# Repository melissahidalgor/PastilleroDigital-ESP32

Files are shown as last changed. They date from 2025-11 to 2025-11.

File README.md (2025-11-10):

# 💊 Proyecto: Pastillero Digital con Web Server 

## Resumen del Proyecto

El Pastillero Digital actúa como como un recordatorio de medicación y un recolector de datos para resolver la problemática de las personas que olvidan tomar sus medicamentos.

El sistema utiliza un microcontrolador ESP32 para controlar los componentes físicos (pantalla, alarma y sensores de peso) y simultáneamente aloja un Web Server para la administración remota de la medicación a través de una página web.

## 💻 Hardware y Componentes

| Componente | Conexión/ Tecnología| Función Principal |
| :--- | :---: | :--- |
| **ESP32 S3** | Microcontrolador | Utilizado por su capacidad Wi-Fi  y alto rendimiento |
| **Galgas** | Puente de Wheatstone / HX711 (ADC) | Sensores de presión que detectan la presencia o el retiro de pastillas en cada compartimento |
| **Pantalla LCD TFT** | LVGL (Librería de GUI) / SPI | Visualiza la hora, fecha y la siguiente pastilla a tomar |
| **Buzzer** | Salida Digital | Activa una alarma sonora cuando llega la hora de la toma |
| **Batería de Litio (250 mAh)** |  | Autonomía para el uso portable |
| **TP4056** |  | Módulo de carga y descarga de batería |

## Desarrollo Web (Web Server)

El ESP32 aloja un servidor web para la administración remota. Se usan SPIFFS (Serial Peripheral Interface Flash File System) para almacenar y servir todos los archivos estáticos de la interfaz web en la ESP32.

| Archivo | Tecnología| Función Principal |
| :--- | :---: | :--- |
| **index.html** | HTML5 |Estructura de la interfaz de usuario |
| **estilos.css** | CSS3 |Estilos y presentación de la página |
| **script.js** | JavaScript |Lógica de negocio: Gestión local (localStorage), cálculo de tomas futuras, y comunicación asíncrona (Fetch) con el ESP32. |

## ⚙️ Características de la Programación 
* **Detección de toma de pastilla:** Se utiliza un algoritmo de detección de cambio por umbral y un tiempo de confirmación de 5 segundos para validar que una pastilla fue retirada.

* **Comunicación Cliente-Servidor:**   `handleRecibirProximaToma()`: Recibe los datos de la próxima dosis desde la página web y los almacena en el ESP32.

  `handleGetTomaNotificacion()`: Permite a la página web hacer polling al ESP32 para saber si se ha detectado una toma física, enviando la confirmación de regreso para actualizar el historial.

* **Gestión de Tiempo:** Se utiliza el protocolo NTP para obtener la hora y fecha actual

* **Interfaz de Usuario Embebida:** Implementación de la librería LVGL para renderizar la interfaz en el LCD TFT

## 🖼️ Montaje

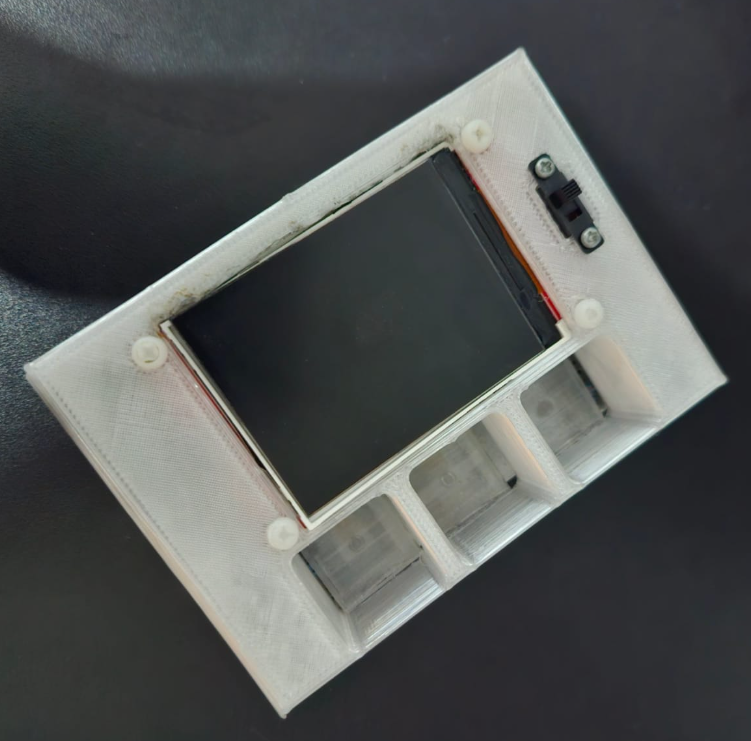
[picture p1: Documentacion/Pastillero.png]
texto alternativo


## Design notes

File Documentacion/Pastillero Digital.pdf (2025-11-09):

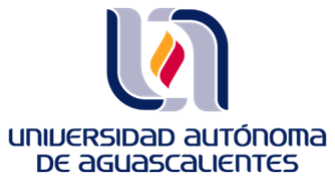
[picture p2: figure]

### CENTRO DE CIENCIAS BÁSICAS

### DEPARTAMENTO DE SISTEMÁS ELECTRÓNICOS

### INGENIERÍA EN ELECTRÓNICA

### CONTROL DISCRETO

## PROYECTO FINAL

## PASTILLERO DIGITAL

INTEGRANTES:

JORGE EDUARDO FUANTOS DÍAZ

MELISSA HIDALGO RODRÍGUEZ

HAEL BARUC MARTINEZ CHAVEZ

DOCENTE: FABIOLA FRAGOSO SALAS

FECHA: 13/06/25

# INDICE

DESCRIPCIÓN DEL PROYECTO:

El pastillero digital es un sistema que cuenta con tres compartimentos para almacenar pastillas, una pantalla LCD para visualizar la siguiente pastilla a ser tomada, sensores de presión para detectar las pastillas y la conexión a una página web para administrar las pastillas tomadas y por tomar.

MOTIVACIÓN:

Nuestro proyecto consistió en crear un pastillero recordatorio y recolector de datos. Nuestra motivación es ofrecer un pastillero con un sistema encargado de recordar la medicación de los usuarios, ser económico, ergonómico y accesible para todo el mercado.
La problemática que solucionamos en gran parte es que las personas mayores pueden tener perdidas de memoria que les impide tomar sus medicamentos a tiempo.

TEMAS DEL CURSO APLICADOS:

El principal tema aplicado fue el muestreo para determinar la frecuencia de muestro en las galgas y para saber el tiempo de polling de la página web a la ESP32.

DESARROLLO DEL PROYECTO:

Para el desarrollo de nuestro proyecto nos enfocamos en 3 fases: planeación, desarrollo e implementación.
En la planeación del proyecto planteamos materiales con los que vamos a trabajar, plan de trabajo, secciones del proyecto y sus riesgos.
Diagramas de bloques para las conexiones eléctricas:

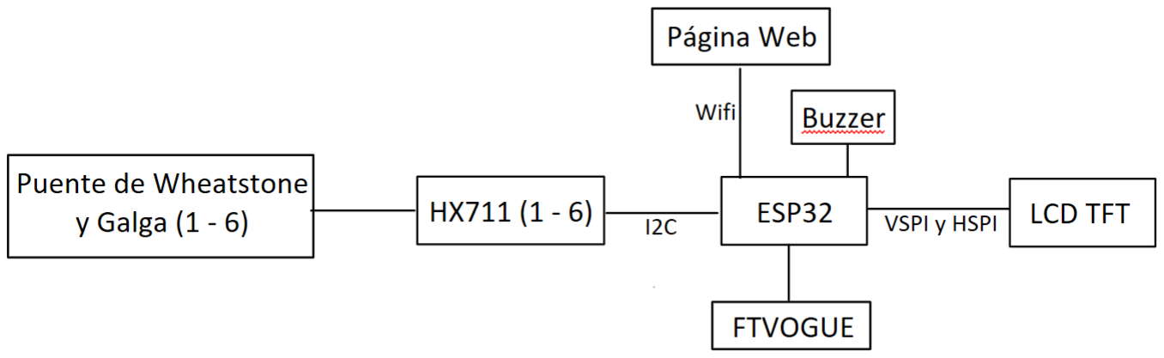
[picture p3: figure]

Figura 1: Diagrama a bloques

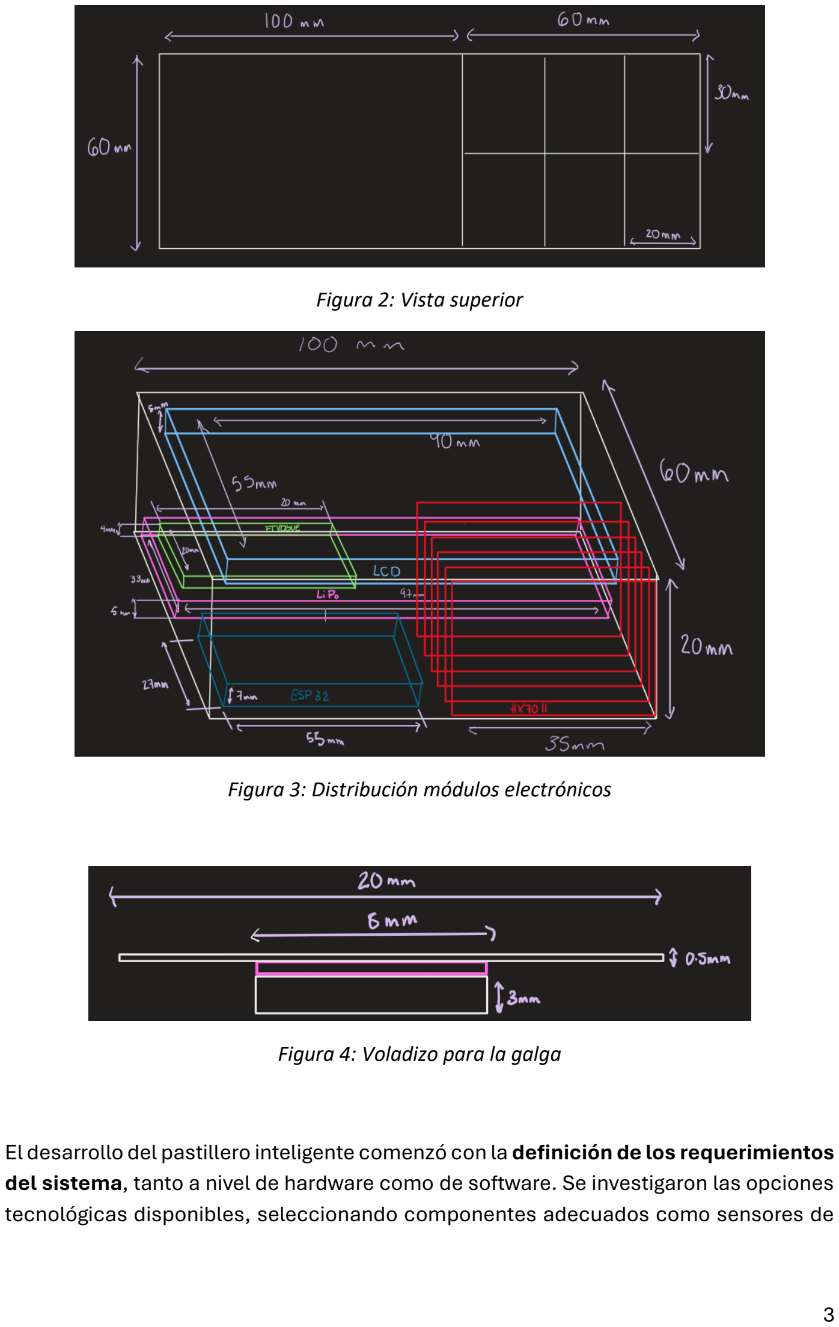
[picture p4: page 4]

Figura 2: Vista superior

Figura 3: Distribución módulos electrónicos

Figura 4: Voladizo para la galga

El desarrollo del pastillero inteligente comenzó con la definición de los requerimientos del sistema, tanto a nivel de hardware como de software. Se investigaron las opciones tecnológicas disponibles, seleccionando componentes adecuados como sensores de peso, pantallas LCD y microcontroladores con conectividad. A partir de ello, se estableció un esquema de funcionamiento general mediante un diagrama de bloques.

Una vez identificados los componentes, se procedió con la revisión de materiales y adquisición de los elementos electrónicos y mecánicos necesarios para los primeros prototipos. Paralelamente, se realizó documentación inicial del proyecto.

Luego, se diseñó el circuito electrónico preliminar, se elaboró un primer boceto físico del pastillero y se planificó la estructura del código con las funcionalidades deseadas. En esta etapa también se modeló en 3D la carcasa del dispositivo, se desarrolló el esquemático del circuito y se inició la creación de la interfaz de usuario.

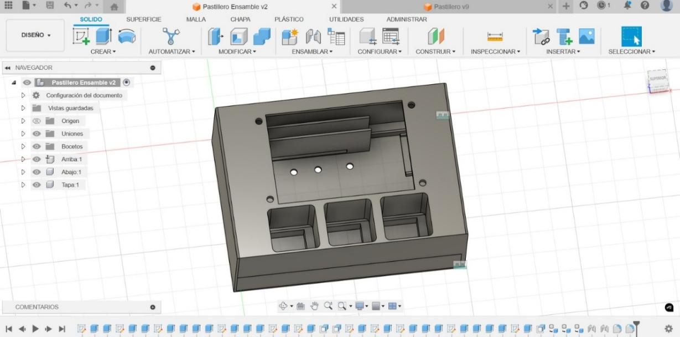
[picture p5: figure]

Figura 5: Diseño del pastillero en 3D

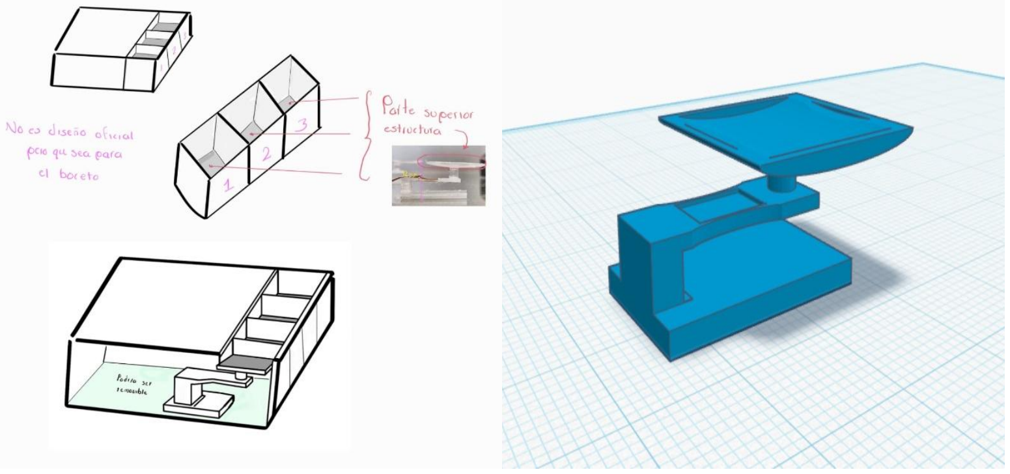
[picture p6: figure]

Figura 6: Diseño del pastillero junto con el sistema de galgas

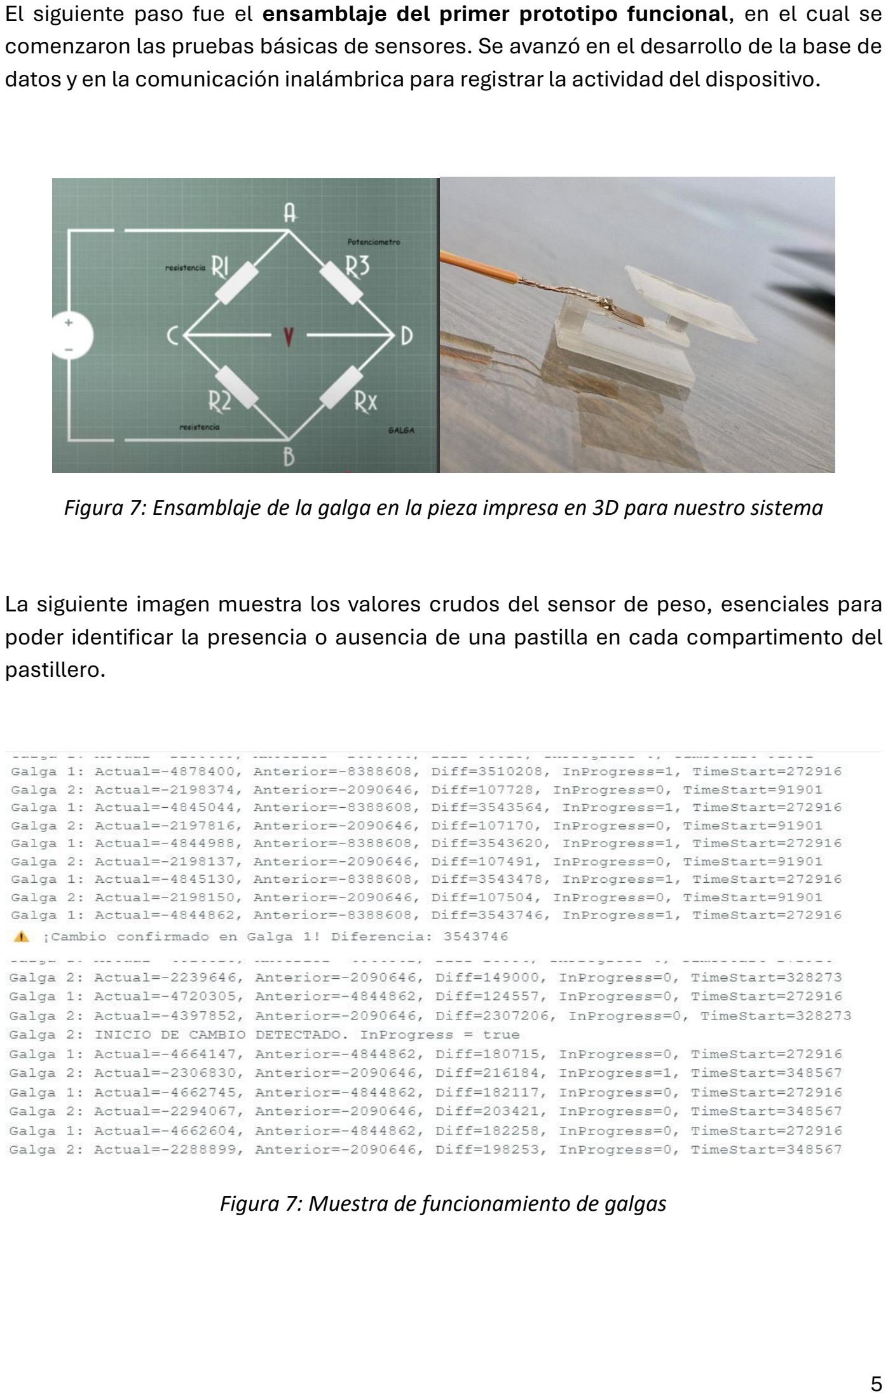
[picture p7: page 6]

El siguiente paso fue el ensamblaje del primer prototipo funcional, en el cual se comenzaron las pruebas básicas de sensores. Se avanzó en el desarrollo de la base de datos y en la comunicación inalámbrica para registrar la actividad del dispositivo.

Figura 7: Ensamblaje de la galga en la pieza impresa en 3D para nuestro sistema

La siguiente imagen muestra los valores crudos del sensor de peso, esenciales para poder identificar la presencia o ausencia de una pastilla en cada compartimento del pastillero.

Figura 7: Muestra de funcionamiento de galgas

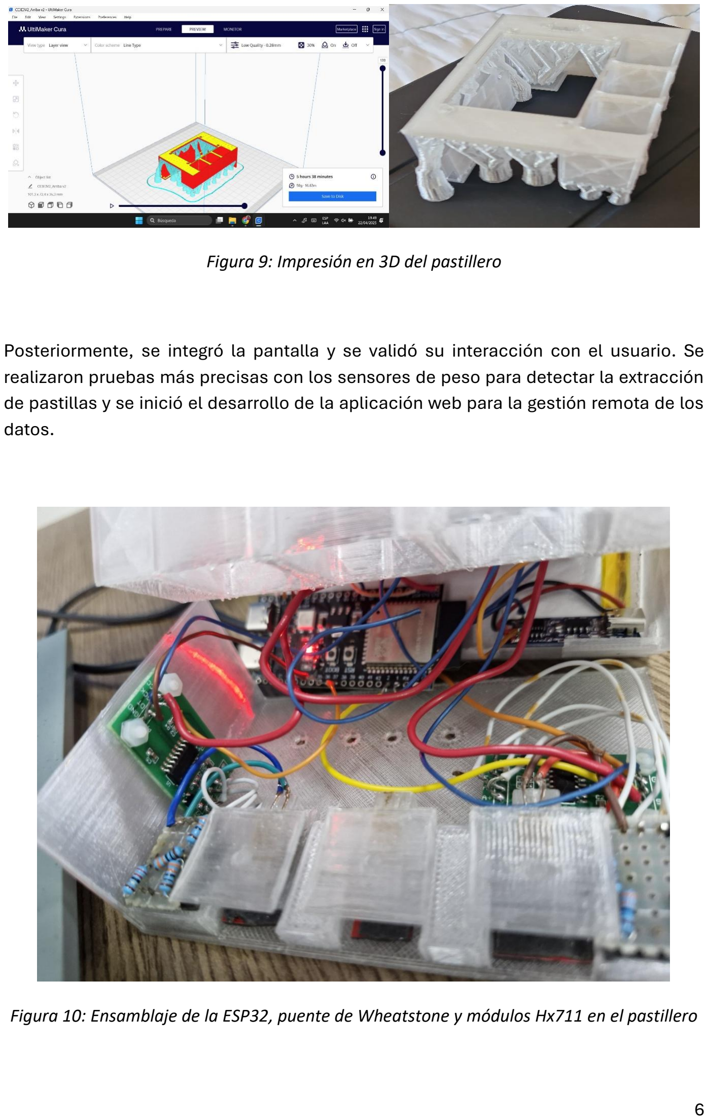
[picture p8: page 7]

Figura 9: Impresión en 3D del pastillero

Posteriormente, se integró la pantalla y se validó su interacción con el usuario. Se realizaron pruebas más precisas con los sensores de peso para detectar la extracción de pastillas y se inició el desarrollo de la aplicación web para la gestión remota de los datos.

Figura 10: Ensamblaje de la ESP32, puente de Wheatstone y módulos Hx711 en el pastillero

Se hicieron ajustes en el código para mejorar la precisión de detección, se implementaron funciones de notificación y alertas. Con el sistema funcionando, se realizaron pruebas funcionales y depuración de errores tanto en el hardware como en el software.

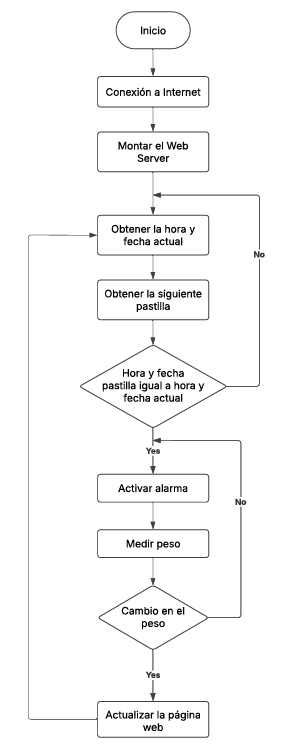
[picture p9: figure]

Figura 11: Diagrama de Flujo del Soft

LECCIONES APRENDIDAS:

- Durante las pruebas, se observó que la interfaz gráfica en pantalla es funcional, aunque podría beneficiarse de una navegación más intuitiva, especialmente para personas mayores o con poca familiaridad con tecnología.
- El uso de la ESP32 permitió una conexión eficiente con la base de datos, aunque sería conveniente explorar alternativas de comunicación más seguras o escalables para una versión comercial.
- La impresión 3D de la carcasa resultó adecuada para prototipado rápido, aunque se detectó que el diseño podría optimizarse en dimensiones y en el tipo de material para hacerlo más duradero y estéticamente agradable.

EVIDENCIA DEL PROYECTO:

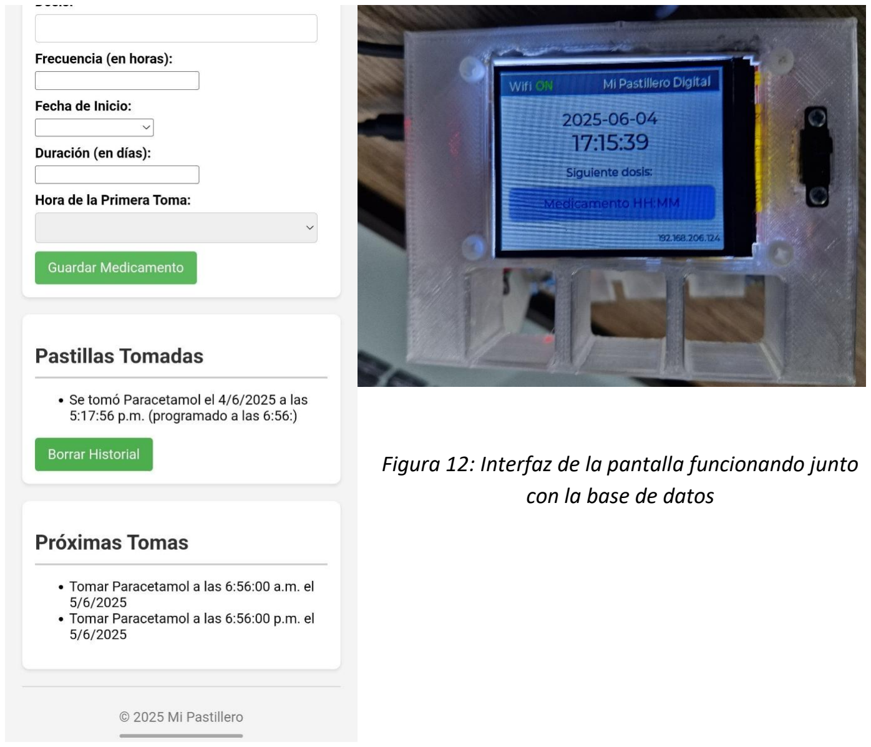
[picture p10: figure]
con la base de datos

Figura 12: Interfaz de la pantalla funcionando junto

SIGUIENTES PASOS O IDEAS FUTURAS:

- Mas espacios de pastillas para toda la semana
- Materiales del pastillero que sean herméticos
- Interfaz más amigable para usuarios y sus médicos

CONCLUCIONES:

El desarrollo del pastillero inteligente permitió aplicar conocimientos teóricos y prácticos de electrónica, programación y diseño 3D para resolver una problemática real relacionada con la salud y el bienestar de personas con necesidades especiales de seguimiento médico.
Gracias a la planificación detallada y la colaboración efectiva del equipo, se logró diseñar un sistema funcional que detecta el retiro de pastillas, registra la actividad y notifica al usuario, con miras a futuras mejoras como ampliar la capacidad del pastillero o hacer más intuitiva la interfaz.
Este proyecto no solo representa un prototipo funcional, sino también una base sólida para continuar hacia una posible producción comercial, con mejoras en diseño, eficiencia energética y usabilidad, teniendo en cuenta la retroalimentación de pruebas con usuarios reales.

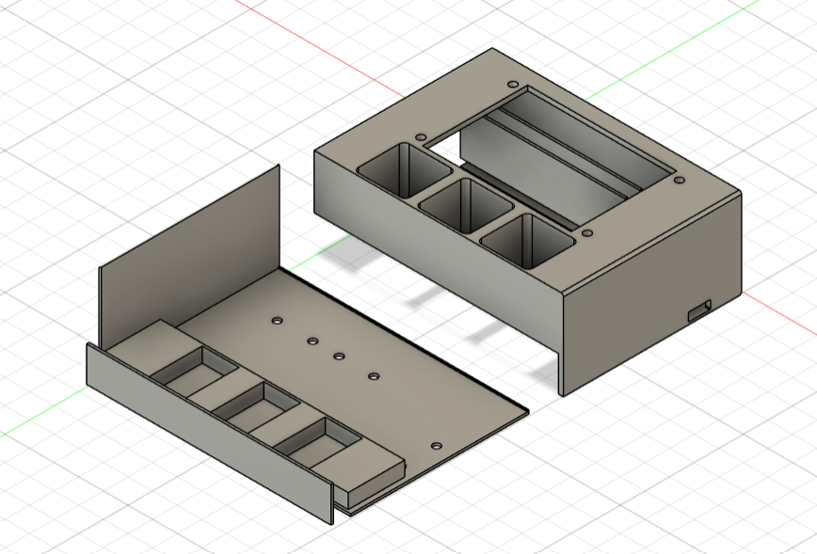
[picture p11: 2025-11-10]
Modelo3D/Piezas.png

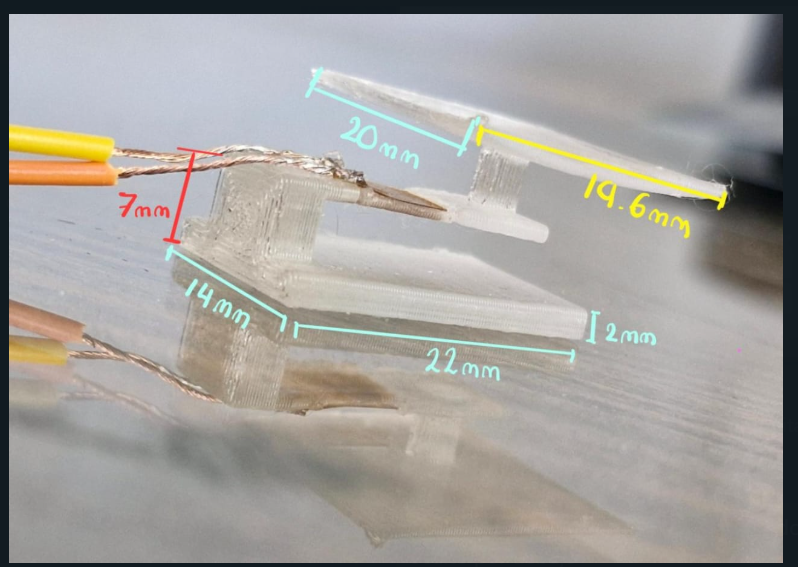
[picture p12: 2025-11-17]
Documentacion/PortaPastilla.png

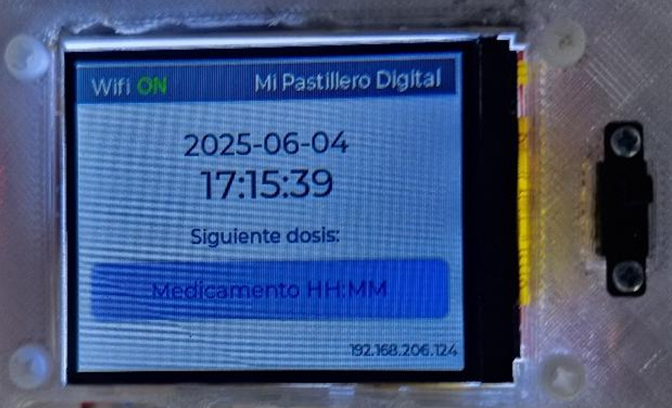
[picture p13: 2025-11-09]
Documentacion/Pantalla.png

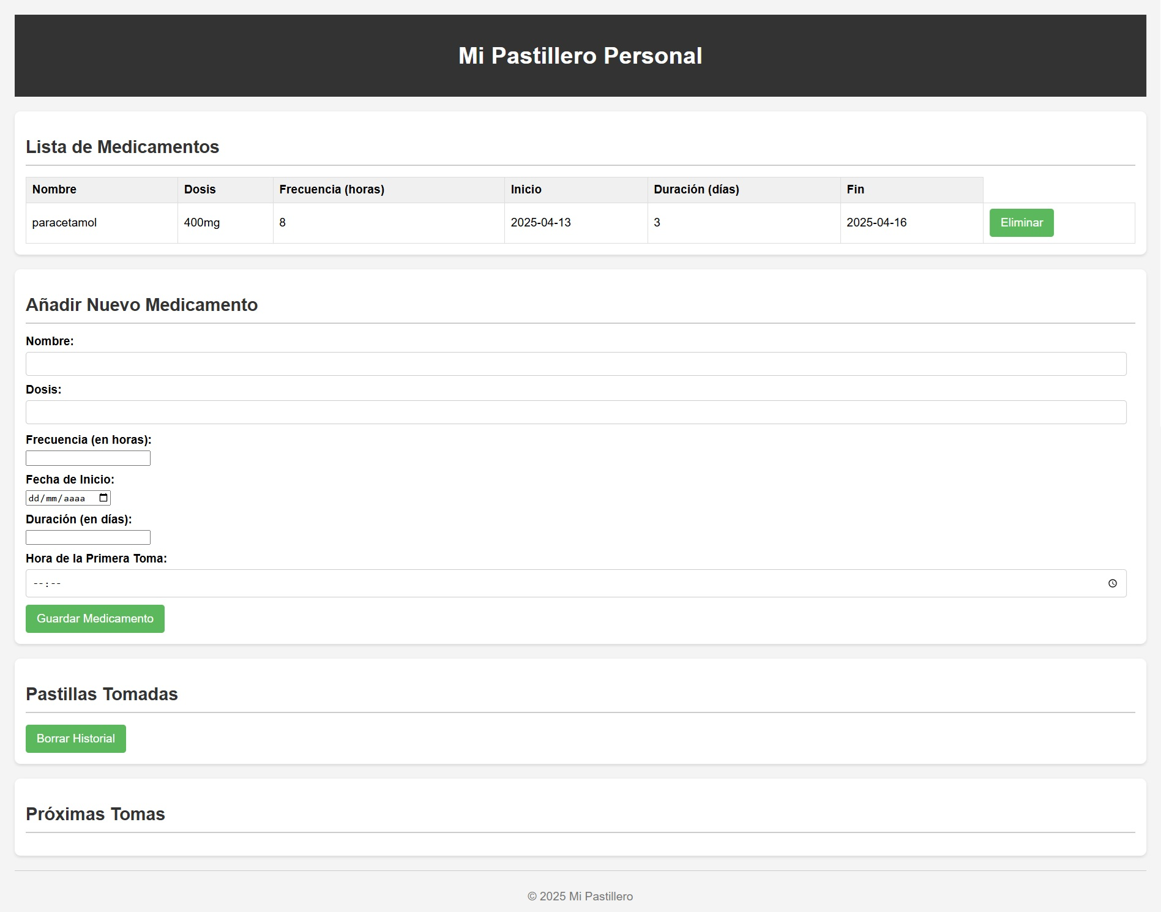
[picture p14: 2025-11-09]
Documentacion/PaginaWeb.png

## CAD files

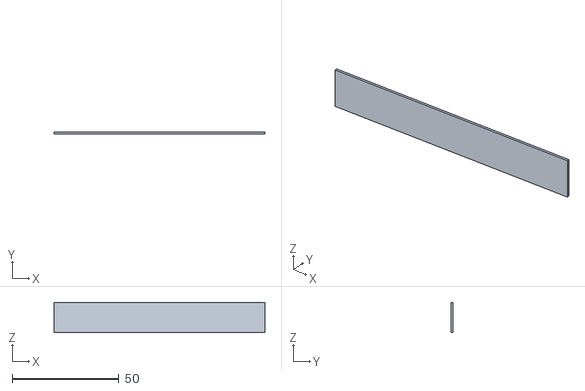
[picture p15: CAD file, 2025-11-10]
Modelo3D/Tapa v3.stl
99.0 x 0.9 x 14.1

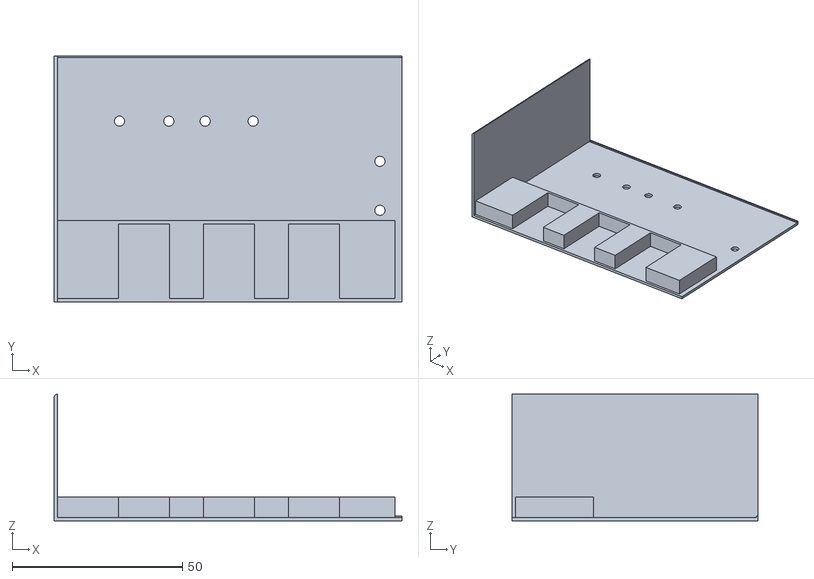
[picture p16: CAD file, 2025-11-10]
Modelo3D/Abajo v1.stl
102.3 x 72.4 x 37.3

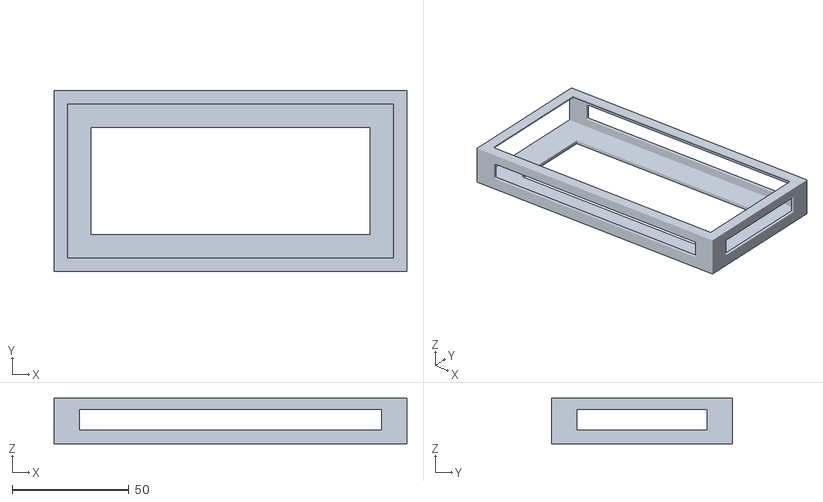
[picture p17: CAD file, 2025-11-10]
Modelo3D/Pila v3.stl
151.2 x 77.6 x 19.7

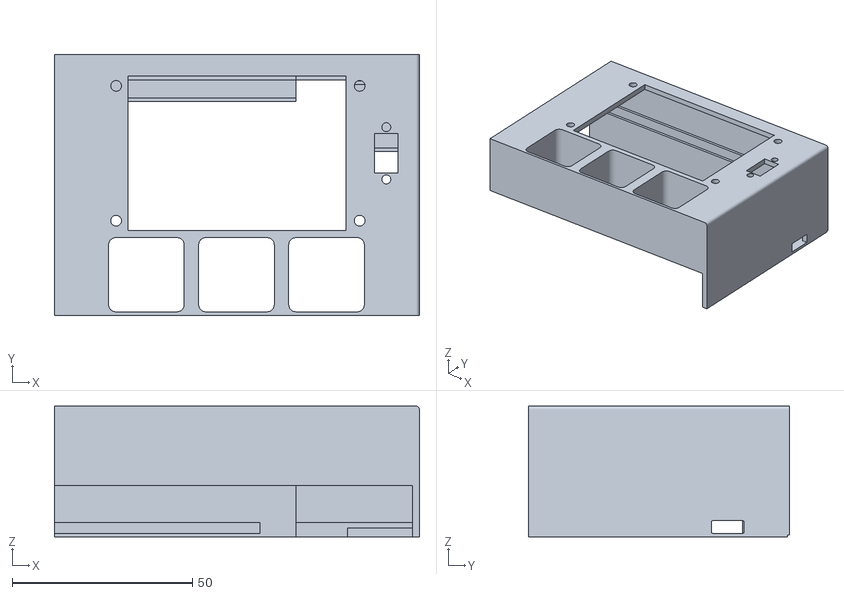
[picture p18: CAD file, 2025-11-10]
Modelo3D/Arriba v4.stl
101.3 x 72.4 x 36.3

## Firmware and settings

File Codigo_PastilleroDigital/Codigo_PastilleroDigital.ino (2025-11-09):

//---------------------------------------- Including Libraries
#include <WiFi.h>
#include <WebServer.h>
#include <FS.h>
#include <SPIFFS.h>
#include "time.h"
#include "miWebServer.h"

#include <lvgl.h>
#include <TFT_eSPI.h>
#include <SPI.h>
#include "ui.h"

#include "HX711.h"

//---------------------------------------- LCD TFT
/* IN USER SETUP

// ESP32 S3 HSPI
VCC
GND
#define TFT_CS   10  // Chip select control pin
#define TFT_RST  -1  // Set TFT_RST to -1 if display RESET is connected to ESP32 board RST
#define TFT_DC   14   // Data Command control pin
#define TFT_MOSI 11
#define TFT_SCLK 12
#define TFT_BL   16           // LED back-light control pin
#define TFT_MISO 13
*/

// ------------------------------- Galgas 
#define DT1 1
#define SCK1 2

#define DT2 36
#define SCK2 37

// ******************************************************************************* Globales
WebServer server(80);
TFT_eSPI tft = TFT_eSPI();

uint8_t* draw_buf;
uint32_t lastTick = 0;

doseInfo nextDose;
bool nuevaTomaDisponible = false;

HX711 scale1;
HX711 scale2;

// Parámetros de configuración
const int num_lecturas = 5;              // Muestras para promedio
const long umbral_diferencia = 330000;     // Cambios mayores a esto son considerados eventos
const unsigned long tiempo_confirmacion = 5000;  // Tiempo mínimo sostenido en ms 

// Variables de estado para las galgas
long promedio_anterior1 = 0;
long promedio_actual1 = 0;
unsigned long tiempo_inicio_diferencia1 = 0;
bool cambio_en_progreso1 = false;

long promedio_anterior2 = 0;
long promedio_actual2 = 0;
unsigned long tiempo_inicio_diferencia2 = 0;
bool cambio_en_progreso2 = false;

long promedio_anterior3 = 0;
long promedio_actual3 = 0;
unsigned long tiempo_inicio_diferencia3 = 0;
bool cambio_en_progreso3 = false;

// ******************************************************************************** Constantes
// Credenciales de Wi-Fi
const char* ssid = "S23 FE de Jorge"; //"Melissa Galaxy A30"; //"dlink_extension";  
const char* password = "Pons2003"; //"isue7235"; //"3YYHxxcCGm";   

// Configuración de hora
const char* ntpServer = "pool.ntp.org";
const long gmtOffset_sec = -21600;  // Time zone for Aguascalientes (UTC-6)
const int daylightOffset_sec = 0;

// LVGL draw into this buffer, 1/10 screen size usually works well. The size is in bytes.
#define SCREEN_WIDTH 320
#define SCREEN_HEIGHT 240
#define DRAW_BUF_SIZE (SCREEN_WIDTH * SCREEN_HEIGHT / 10 * (LV_COLOR_DEPTH / 8))

// ****************************************************************************** Funciones Externas
extern void handleRoot();
extern void handleCSS();
extern void handleJS();
extern void handleRecibirProximaToma();

//**********************************************************************************************************************************
//________________________________________________________________________________ log_print()
// If logging is enabled, it will inform the user about what is happening in the library.
void log_print(lv_log_level_t level, const char* buf) {
  LV_UNUSED(level);
  Serial.println(buf);
  Serial.flush();
}

//________________________________________________________________________________ touchscreen_read() Dummy
// Get the Touchscreen data.
void touchscreen_read(lv_indev_t* indev, lv_indev_data_t* data) {
  // Serial.println("No hay touch");
}
//**********************************************************************************************************************************
//_____________________________________________________________________________________________________________ setup()
void setup() {
  Serial.begin(115200);
  delay(3000);
  // ___________________________________________________________ TFT begin
  // Start the tft display
  tft.init();
  // Set the TFT display rotation in landscape mode
  tft.setRotation(1);
  Serial.println("Pantalla TFT configurada");

  // ___________________________________________________________ LVGL begin
  // Start LVGL.
  lv_init();

  // Register print function for debugging.
  lv_log_register_print_cb(log_print);

  // Create a display object.
  lv_display_t* disp;

  // Initialize the TFT display using the TFT_eSPI library.
  draw_buf = new uint8_t[DRAW_BUF_SIZE];
  disp = lv_tft_espi_create(SCREEN_HEIGHT, SCREEN_WIDTH, draw_buf, DRAW_BUF_SIZE);
  lv_display_set_rotation(disp, LV_DISPLAY_ROTATION_90);

  // Initialize an LVGL input device object (Touchscreen).
  lv_indev_t* indev = lv_indev_create();
  lv_indev_set_type(indev, LV_INDEV_TYPE_POINTER);

  // Set the callback function to read Touchscreen input.
  lv_indev_set_read_cb(indev, touchscreen_read);

  // Integrate EEZ Studio GUI.
  ui_init();

  // Register event handler.
  Serial.println("LVGL configurado");

  // ___________________________________________________________ SPIFFS begin
  if (!SPIFFS.begin()) {
    Serial.println("¡Error al montar SPIFFS!");
    return;
  }
  // ___________________________________________________________ WiFi begin
  WiFi.begin(ssid, password);
  Serial.print("Conectando a Wi-Fi");
  while (WiFi.status() != WL_CONNECTED) {
    delay(500);
    Serial.print(".");
    lv_label_set_text(objects.label_wifi_status, "CONECTANDO");
  }
  lv_label_set_text(objects.label_wifi_status, "ON");
  Serial.println("");
  Serial.print("Conectado a la red Wi-Fi con IP: ");
  Serial.println(WiFi.localIP());
  lv_label_set_text(objects.label_ip, WiFi.localIP().toString().c_str());

  // ___________________________________________________________ Server begin
  server.on("/", handleRoot);
  server.on("/estilos.css", HTTP_GET, handleCSS);
  server.on("/script.js", HTTP_GET, handleJS);
  server.on("/recibir_proxima_toma", HTTP_GET, handleRecibirProximaToma);
  server.on("/get_toma_notificacion", handleGetTomaNotificacion);
  server.begin();
  Serial.println("Servidor web iniciado");
  // ___________________________________________________________ Time begin
  configTime(gmtOffset_sec, daylightOffset_sec, ntpServer);
  Serial.println("Tiempo configurado");
  // ___________________________________________________________ Galga begin
  scale1.begin(DT1, SCK1);
  scale2.begin(DT2, SCK2);
  Serial.println("Galgas iniciadas");

  promedio_anterior1 = obtener_promedio_crudo(scale1, num_lecturas);
  promedio_anterior2 = obtener_promedio_crudo(scale2, num_lecturas);
}

//_____________________________________________________________________________________________________________ loop()
void loop() {
  server.handleClient();

  promedio_actual1 = obtener_promedio_crudo(scale1, num_lecturas);
  promedio_actual2 = obtener_promedio_crudo(scale2, num_lecturas);

  detectar_cambio_galga(1, promedio_actual1, promedio_anterior1, cambio_en_progreso1, tiempo_inicio_diferencia1);
  detectar_cambio_galga(2, promedio_actual2, promedio_anterior2, cambio_en_progreso2, tiempo_inicio_diferencia2);

  lv_tick_inc(millis() - lastTick);
  lastTick = millis();
  lv_timer_handler();
  //delay(5);

  // Actualizar cada segundo (1000 milisegundos)
  static unsigned long lastUpdateTime = 0;
  if (millis() - lastUpdateTime >= 1000) {
    getDateTime();
    lastUpdateTime = millis();
  }
}

//__________________________________________________________________________________ getDateTime()
void getDateTime() {
  struct tm timeinfo;  // Fecha actual

  if (getLocalTime(&timeinfo)) {
    char fechaStr[11];  // YYYY-MM-DD
    strftime(fechaStr, sizeof(fechaStr), "%Y-%m-%d", &timeinfo);
    //Serial.println(fechaStr);
    lv_label_set_text(objects.label_date, fechaStr);

    char horaStrCompleta[9];  // HH:MM:SS
    strftime(horaStrCompleta, sizeof(horaStrCompleta), "%H:%M:%S", &timeinfo);
    //Serial.println(horaStrCompleta);
    lv_label_set_text(objects.label_time, horaStrCompleta);

    // ------- Alarma
    char horaStrCorta[7];  // HH:MM
    strftime(horaStrCorta, sizeof(horaStrCorta), "%H:%M", &timeinfo);
    String fechaActual = String(fechaStr);
    String horaActual = String(horaStrCorta);

    if (fechaActual.equals(nextDose.fecha)) {
      if (horaActual.equals(nextDose.hora) && !nuevaTomaDisponible) {
        Serial.println("Alarma: Tomar " + nextDose.nombre);

        lv_label_set_text(objects.label_alarma_time, horaStrCorta);
        lv_label_set_text(objects.label_alarma_dose, nextDose.nombre.c_str());
        //lv_label_set_text(objects.label_notas, nextDose.notas.c_str());

        lv_obj_add_flag(objects.main, LV_OBJ_FLAG_HIDDEN);      // Oculta la pantalla principal
        lv_obj_clear_flag(objects.alarma, LV_OBJ_FLAG_HIDDEN);  // Muestra la pantalla de la alrma
        lv_scr_load(objects.alarma);                            // Carga la pantalla de historial
      } else {
        lv_obj_add_flag(objects.alarma, LV_OBJ_FLAG_HIDDEN);  // Oculta la pantalla de alarma
        lv_obj_clear_flag(objects.main, LV_OBJ_FLAG_HIDDEN);  // Muestra la pantalla principal
        lv_scr_load(objects.main);                            // Carga la pantalla principal

        int horaActualInt = horaActual.substring(0, 2).toInt();   
        int minutoActualInt = horaActual.substring(3, 5).toInt();
        int horaNextDoseInt = nextDose.hora.substring(0, 2).toInt();
        int minutoNextDoseInt = nextDose.hora.substring(3, 5).toInt();

       if (horaActualInt > horaNextDoseInt || (horaActualInt == horaNextDoseInt && minutoActualInt > minutoNextDoseInt)) {
        Serial.println("Desfase de hora");
        nextDose.nombre = "";
        nextDose.hora = "";
        nextDose.fecha = "";
        }
      }
    } 
  } else {
    //Serial.println("Error al obtener la hora");
    lv_label_set_text(objects.label_date, "Conectando");
    lv_label_set_text(objects.label_time, "Conectando");
  }
}
//________________________________________________________________________________ obtener_promedio_crudo() 
long obtener_promedio_crudo(HX711 &scale, int n) {
  long suma = 0;
  for (int i = 0; i < n; i++) {
    suma += scale.read();
    delay(2); // Retardo más corto por lectura individual
  }
  return suma / n;
}

//________________________________________________________________________________ detectar_cambio() 
void detectar_cambio_galga(int galga_num, long promedio_actual, long &promedio_anterior, bool &cambio_en_progreso, unsigned long &tiempo_inicio_diferencia) {
  long diferencia = abs(promedio_actual - promedio_anterior);

  Serial.printf("Galga %d: Actual=%ld, Anterior=%ld, Diff=%ld, InProgress=%d, TimeStart=%ld\n",
                galga_num, promedio_actual, promedio_anterior, diferencia, cambio_en_progreso, tiempo_inicio_diferencia);

  if (diferencia > umbral_diferencia) {
    if (!cambio_en_progreso) {
      tiempo_inicio_diferencia = millis();
      cambio_en_progreso = true;
      Serial.printf("Galga %d: INICIO DE CAMBIO DETECTADO. InProgress = true\n", galga_num);
    } else if (millis() - tiempo_inicio_diferencia >= tiempo_confirmacion) {
      Serial.printf("⚠️ ¡Cambio confirmado en Galga %d! Diferencia: %ld\n", galga_num, diferencia);
      promedio_anterior = promedio_actual;
      cambio_en_progreso = false;
      nuevaTomaDisponible = true;
      delay(7000);
    }
  } else {
    cambio_en_progreso = false;
  }
}

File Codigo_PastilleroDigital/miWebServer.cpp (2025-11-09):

#include "miWebServer.h" 

extern WebServer server;
extern doseInfo nextDose;
extern bool nuevaTomaDisponible;
//________________________________________________________________________________ handleRoot()
void handleRoot() {
  File file = SPIFFS.open("/index.html", "r");
  if (file) {
    server.streamFile(file, "text/html");
    file.close();
  } else {
    server.send(404, "text/plain", "Archivo no encontrado");
  }
}
//________________________________________________________________________________ handleCSS()
void handleCSS() {
  File file = SPIFFS.open("/estilos.css", "r");
  if (file) {
    server.streamFile(file, "text/css");
    file.close();
  } else {
    server.send(404, "text/plain", "Archivo CSS no encontrado");
  }
}
//________________________________________________________________________________ handleJS()
void handleJS() {
  File file = SPIFFS.open("/script.js", "r");
  if (file) {
    server.streamFile(file, "application/javascript");
    file.close();
  } else {
    server.send(404, "text/plain", "Archivo JS no encontrado");
  }
}
//________________________________________________________________________________ handleRecibirProximaToma()
void handleRecibirProximaToma() {
  if (server.hasArg("nombre") || server.hasArg("hora") || server.hasArg("fecha")) {
    if(server.arg("nombre") != nextDose.nombre || server.arg("hora") != nextDose.hora){
      nextDose.nombre = server.arg("nombre");
      nextDose.hora = server.arg("hora");
      nextDose.fecha = server.arg("fecha");
    
      String proximaTomaRecibida =  nextDose.nombre + " " + nextDose.hora;
      lv_label_set_text(objects.label_next_dose, proximaTomaRecibida.c_str());
      Serial.println("Próxima toma recibida: " + proximaTomaRecibida);
      server.send(200, "text/plain", "Próxima toma recibida y almacenada en el ESP32.");
    } else { 
      Serial.println("Sin cambios en la siguiente toma");
      server.send(200, "text/plain", "Sin cambios en la siguiente toma");
    }
  } else {
    server.send(400, "text/plain", "Parámetros incorrectos para la próxima toma.");
  }
}
//________________________________________________________________________________ handleGetTomaNotificación()
void handleGetTomaNotificacion() {
    if (nuevaTomaDisponible) {
        server.send(200, "text/plain", "toma_realizada"); // Enviar un simple indicador
        Serial.println("Se envio toma_realizada");
        nuevaTomaDisponible = false;
    } else {
        server.send(200, "text/plain", "");
    }
}
